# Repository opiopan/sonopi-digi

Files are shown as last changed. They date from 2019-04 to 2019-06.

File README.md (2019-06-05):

Sonopi Digi
===


board image

Sonopi Digi is a hat card for Raspberry Pi to add a S/PDIF digital sound output capability.<br>
This hardware design is published under open source lincence. You can use and modify this design freely. There is also no limitation in commercial use.

In order to export digital sound signal, [Cirrus Logic WM8804](https://www.cirrus.com/products/wm8804/) is installed on Sonopi Digi as a S/PDIF transmitter.
There are many kind of Raspberry Pi Hats installed WM8804 in the world. This IC is a defacto standard to add a S/PDIF output functionality to Raspberry Pi.

## Design Goals
1. **Target to casual use and reasonable cost**<br>
Sonopy Digi is not a device for audiophiles. It's a just simple solution to realize connectivity to audio amplifier without serious noise. I don't expect to install expensive parts and also don't expect to stick to beautiful circuit patterning to improve analog characteristics.<br>
Sonopi Digi should be realized with minimum components, and should be eliminated analog circuit portion. Therefore, only optical output is installed on this product. An coaxial output which need analog driver circuit is not suitable to Sonopi Digi design policy.

2. **Not necessory any additional software**<br>
I don't want to make any software to use Sonopy Digi. Sonopi Digi should be designed to work by using standard device driver and standard device tree overlay configuration.<br>
Specifically, Sonopi Digi is designed to work when following line is added to `/boot/config.txt`.

    ```
    dtoverlay=hifiberry-digi
    ```

## Design Overview
The keypoint of Sonopi Digi hardware design is configuring WM8804 to adapt to following device driver and device tree configuration.

- [hifiberry-digi-overlay.dts](https://github.com/raspberrypi/linux/blob/e2d2941326922b63d722ebc46520c3a2287b675f/arch/arm/boot/dts/overlays/hifiberry-digi-overlay.dts)
- [rpi-wm8804-soundcard.c](https://github.com/raspberrypi/linux/blob/e2d2941326922b63d722ebc46520c3a2287b675f/sound/soc/bcm/rpi-wm8804-soundcard.c)

These files shows following condition regarding WM8804 configuration.

- Must be driven 27MHz crystal oscillation circuit
- Must be configureed with 2 wire software mode.
- I2C device address must be 0x3b

That means WM8804 pin condition should be as below.

WM8804 PIN        |   Configuration
------------------|-------------------------------------------------
XIN(11), XOP(10)  | 27MHz crystal
RSTB(6)           | Pull up to 3.3V
SDIN(3)           | Raspberry Pi I2C1 SDA pin
GPO0(2)           | Pull down to GND
CSB(5)            | Pull up to 3.3V
SCLK(1)           | Raspberry Pi I2C1 SCL
BCLK(14)          | Raspberry Pi I2S BCLK
LRCLK(15)         | Raspberry Pi I2S LRCLK
DIN(13)           | Raspberry Pi I2S DOUT
TXO(17)           | Optical S/PDIF transmitter module

## PoC Result
The PoC is concluded with great success.

<p align="center">
PoC board
</p>

## PCB Design
<p align="center">
PCB schema
</p>
<p align="center">
PCB image
</p>

- **Gerber Data**<br>
Eagle PCB design files are placed at [here](./pcb/). You can also use [this gerber file archive](https://raw.githubusercontent.com/wiki/opiopan/sonopi-digi/data/sonopi-digi-gerber-1.1.zip) to order PCB production.

- **BOM**<br>
    
    Components | Value / Product Number | Remarks
    -----------|------------------------|------------------------------
    IC1        | Cirrus Logic WM8804    |
    X1         | 27MHz Crystal (3225)   | load capacitance: 15pF
    R1         | BCN164AB103J7          | resistor array 10K ohm x 4
    C1, C5     | 1uF (1608)             |
    C2         | 0.1uF (1608)           |
    C3, C4     | 27pF (1608)            | need to change value if X1's load capacitance is not 15pF
    J1         | PLT133/T10W            | optical S/PDIF transmitter

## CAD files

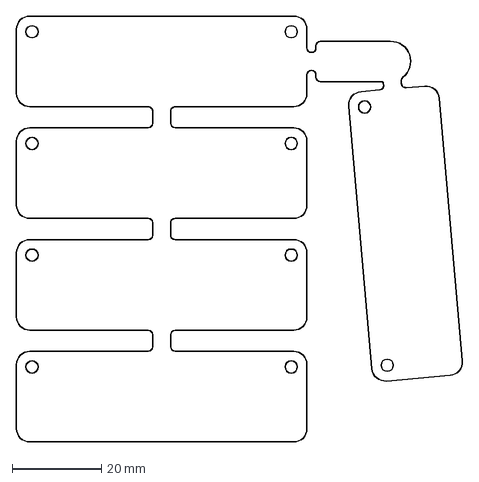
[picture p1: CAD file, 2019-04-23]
panelize/outline.dxf
99.8 x 95.3 mm

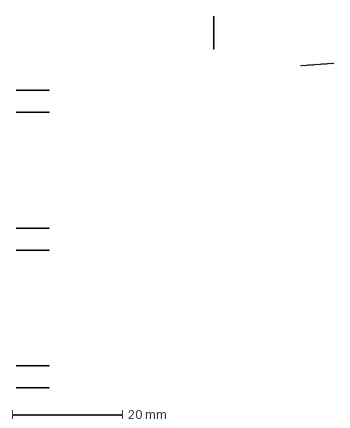
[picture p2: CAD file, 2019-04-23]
panelize/mousebites.dxf
57.7 x 67.5 mm

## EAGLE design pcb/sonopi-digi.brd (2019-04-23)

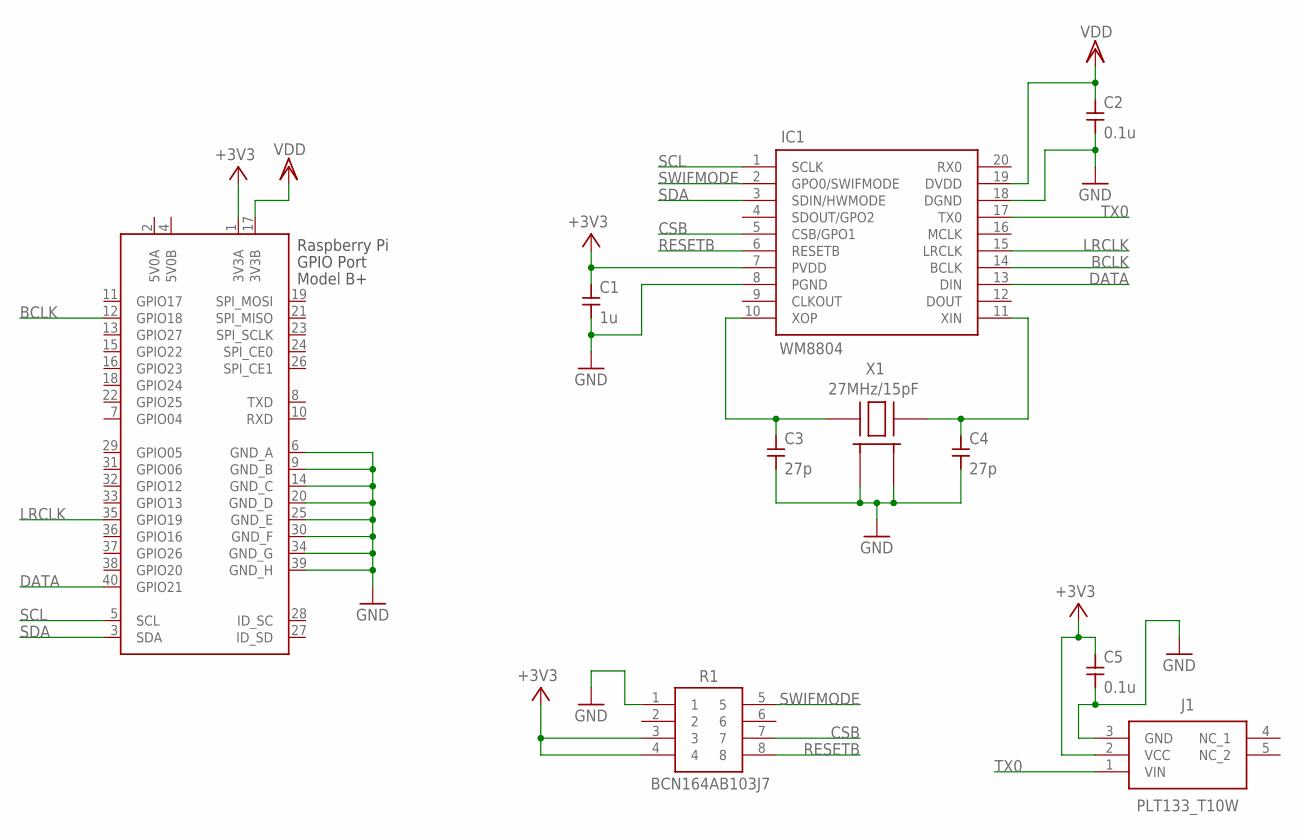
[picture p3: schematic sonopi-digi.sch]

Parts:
C1: 1u; SMD1608
C2, C5: 0.1u; SMD1608
C3, C4: 27p; SMD1608
IC1: WM8804; SOP65P780X200-20N
J1: PLT133_T10W; PLT133T10W
J2: RASPI_BOARD_B+#_SMALL; RASPI_BOARD_B+HAT_SMALL
R1: BCN164AB103J7; BCN164A_1
X1: 27MHz/15pF; CRYSTAL3225-HS

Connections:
5V0A: J2.2 (5V0A)
5V0B: J2.4 (5V0B)
+3V3: C1.1, C5.1, IC1.7 (PVDD), J1.2 (VCC), J2.1 (3V3A), R1.3, R1.4
BCLK: IC1.14 (BCLK), J2.12 (GPIO18)
CSB: IC1.5 (CSB/GPO1), R1.7
DATA: IC1.13 (DIN), J2.40 (GPIO21)
GND: C1.2, C2.2, C3.2, C4.2, C5.2, IC1.8 (PGND), IC1.18 (DGND), J1.3 (GND), J2.6 (GND_A), J2.9 (GND_B), J2.14 (GND_C), J2.20 (GND_D), J2.25 (GND_E), J2.30 (GND_F), J2.34 (GND_G), J2.39 (GND_H), R1.1, X1.2 (GND_1), X1.4 (GND_2)
LRCLK: IC1.15 (LRCLK), J2.35 (GPIO19)
RESETB: IC1.6 (RESETB), R1.8
SCL: IC1.1 (SCLK), J2.5 (SCL)
SDA: IC1.3 (SDIN/HWMODE), J2.3 (SDA)
SWIFMODE: IC1.2 (GPO0/SWIFMODE), R1.5
TX0: IC1.17 (TX0), J1.1 (VIN)
VDD: C2.1, IC1.19 (DVDD), J2.17 (3V3B)
XIN: C4.1, IC1.11 (XIN), X1.3 (HOT_2)
XOP: C3.1, IC1.10 (XOP), X1.1 (HOT_1)

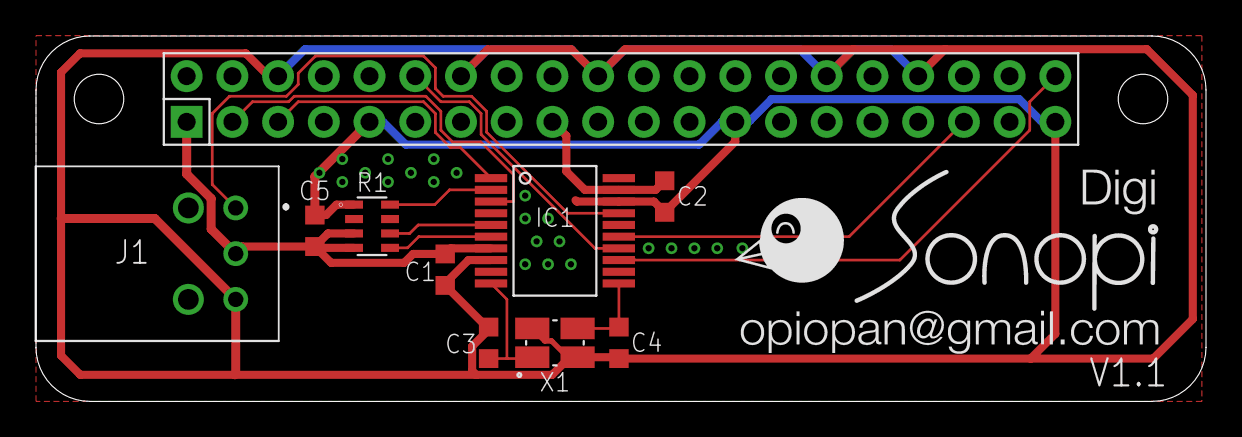
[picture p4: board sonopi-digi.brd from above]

Board: 2 copper layers, 65.0 x 20.3 mm, 11 parts (0 on the bottom side), 14 nets.

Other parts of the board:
U$1: SONOPI-DIGI-LOGO

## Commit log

2019-03-01 add pcb design
    [sonopi-digi.brd, sonopi-digi.sch]
2019-03-03 complete PCB design
    [sonopi-digi.brd, sonopi-digi.sch]
2019-03-04 improve wiring
    [sonopi-digi.brd, sonopi-digi.sch]
2019-03-31 add panelizing script
    [sonopi-digi.brd]
2019-03-31 fix a minor issue
    [fill.dxf, mousebites.dxf, outline.dxf]
2019-04-23 fix a S/PDIF transmitter pin assign issue
    [fill.dxf, mousebites.dxf, outline.dxf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]
2026-10-03 Convert the files from the iDraw format to SVG before Rosetta 2 is omitted in macOS 28 and Autodesk Graphic can no longer be launched.
    [fill.dxf]
